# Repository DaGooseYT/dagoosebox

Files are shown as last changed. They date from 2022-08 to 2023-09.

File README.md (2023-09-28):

# DaGoose Box
<p align="center">
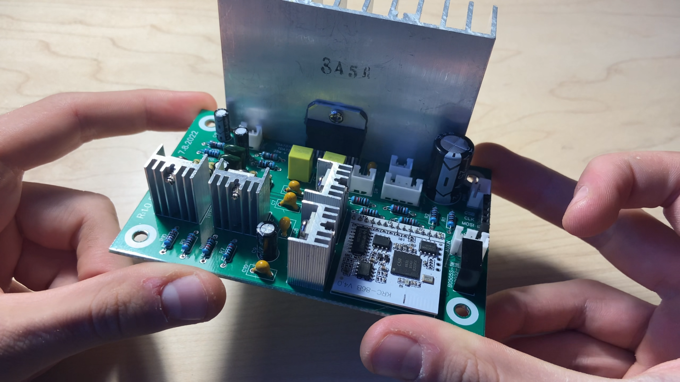
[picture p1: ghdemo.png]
  
</p>

A Hi-Fi linear Class AB amplifier with Bluetooth v4.0 compatibility and enhanced/3D stereo playback. Watch the video guide about it here: https://youtu.be/7peg0jiGp7A

## Features
- Very low THD (~0.02% @8ohm)
- High output power (~25.7w x2 @4ohm)
- Low cost design
- Simple PCB layout
- PCB uses very common passive componants

## Component list
- For the PCB components, please see the BoM located in `/BoM`

- Black box ($9.58): https://amzn.to/3PJ2Jeg
- 5.5mm barrel plug (~$0.60 each): https://amzn.to/3K8r4Zr 
- TDA7375AV ($6.43): https://bit.ly/3K4w6Go
- Heatsinks (~$3.00): No link since they came from salvaged electronics. Price is an estimated value.
- B0505S-1W (~$2.40 each): https://amzn.to/3wcbdDy
- KRC-86B v4.0 ($9.99): https://amzn.to/3pxKD3W
- Power switch (~$0.47 each): https://amzn.to/3AyoTv9
- Other PCB componants (~$6.00 total): No link since there are a variety of passive components. Price is an estimated value.
- 3.5mm audio jack (~$1.75 each): https://amzn.to/3AymmkJ
- Speaker wire terminals ($4.19): https://amzn.to/3QCLaxC
- TIP31C (x2, $1.46): https://bit.ly/3c4znce
- Custom PCB (~$4.00): Price is an estimated average and can vary on the basis of where you get it manufactured and other characteristics such as the solder mask. 

Estimated total component cost (No tax or shipping costs included): $49.87 USD<br />
*All components were priced on 7/25/2022. Prices of the components above are subject to change according to each seller's policies and inflation.<br />

You will also need a 16v 4.5A power supply. This is not calculated in the price list above. Here is the one I used for this project: https://amzn.to/3c4339q

## Mechanical info

- Box hole dimensions (measured from center of holes): 97mm x 56mm
- PCB board dimensions: 110mm x 70mm
- PCB screw holes diameter: 4mm
- Heatsink clearance in box (L x W x H): 84mm x 25mm x 76mm
- Required drill bits: 5mm, 8mm, 12mm

## Licensing
This repository is licensed under the GPL v3.0 license. Any images in this repository are licensed under CC BY-SA 3.0.

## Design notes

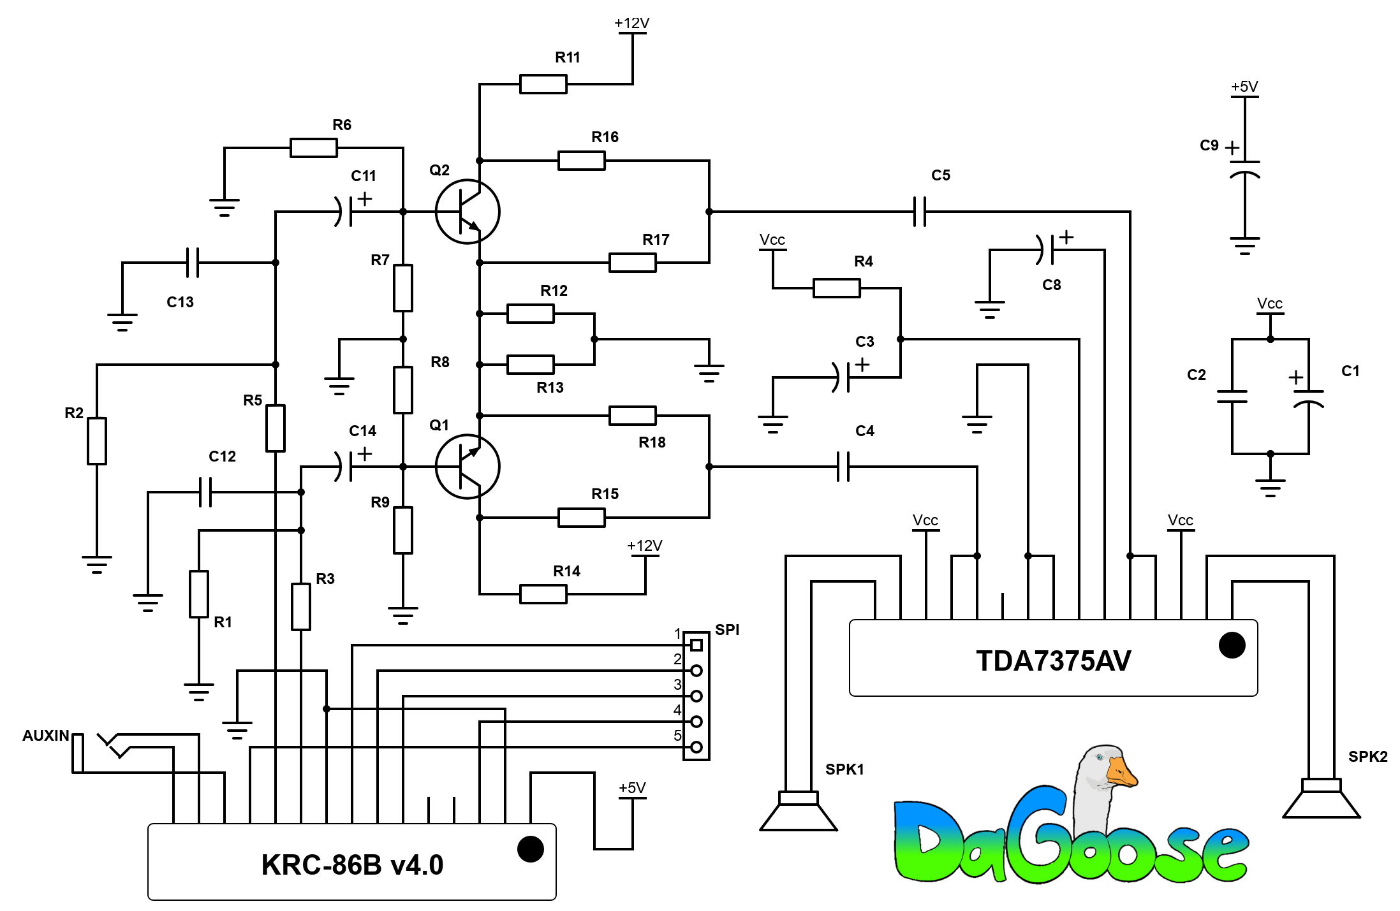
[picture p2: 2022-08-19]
schematic/schematic.png

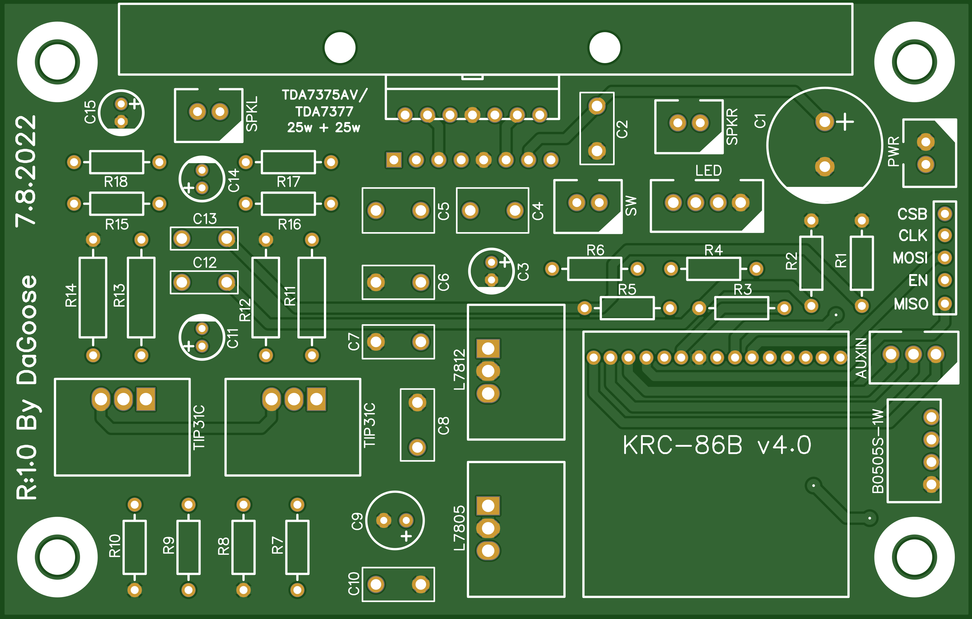
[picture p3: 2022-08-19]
PCB/top.png

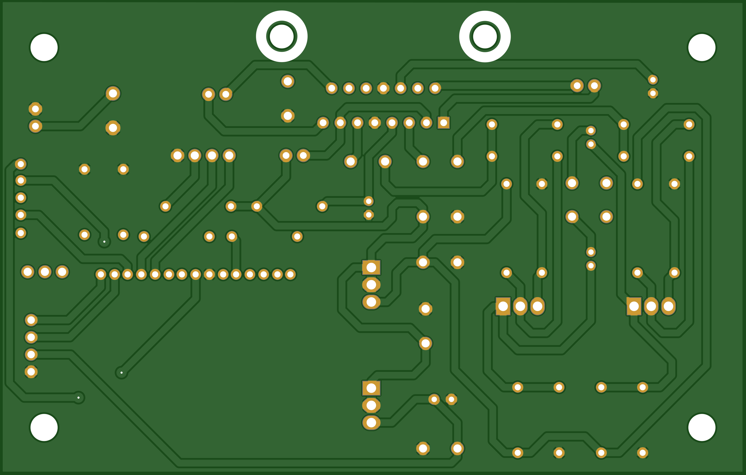
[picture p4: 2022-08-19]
PCB/bottom.png

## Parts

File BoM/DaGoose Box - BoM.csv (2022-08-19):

Componant | Description | Quantity | Manufacturer | Manufacturer Part Number | Additional Comment
R1, R2 | 1KΩ 1/4w ±1% | 2 | - | - | -
R3, R5 | 120Ω 1/4w ±1% | 2 | - | - | -
R4, R6, R7, R8, R9, R10 | 10KΩ 1/4w ±1% | 6 | - | - | -
R11, R12, R13, R14 | 56Ω 1/2w ±1% | 4 | - | - | -
R15, R16 | 100Ω 1/4w ±1% | 2 | - | - | -
R17, R18 | 8.2Ω 1/4w ±1% | 2 | - | - | -
C1 | 2200uF 25v ±10% | 1 | - | - | Electrolytic
C2, C6, C7, C8, C10 | 100nF 100v ±10% | 5 | - | - | Ceramic
C3, C11, C14 | 10uF 50v ±10% | 3 | - | - | Electrolytic
C4, C5 | 1uF 100v ±10% | 2 | - | - | CBB/Polyester Film
C9 | 470uF 10v ±10% | 1 | - | - | Electrolytic
C12, C13 | 33nF 100v ±10% | 2 | - | - | Polyester Film
C15 | 47uF 25v ±10% | 1 | - | - | Electrolytic
TIP31C | High power NPN transistor | 2 | STMicroelectronics | TIP31C | Used with small TO-220 heat sink (optional)
L7812 | 12v linear voltage regulator | 1 | STMicroelectronics | L7812 | Used with small TO-220 heat sink (required)
L7805 | 5v linear voltage regulator | 1 | STMicroelectronics | L7805 | Used with small TO-220 heat sink (optional)
B0505S-1W | 5v power isolator | 1 | K-CUT | B0505S-1WR3 | -
KRC-86B v4.0 | Bluetooth v4.0 module | 1 | - | KRC-86B v4.0 | Used 1x15 2mm pitch pin headers
TDA7375AV | 2x37w linear power amplifier | 1 | STMicroelectronics | E-TDA7375AV | Avoid buying fakes! Only buy from authorized distributors
SPKL, SPKR, SW, PWR | 1x2 2.54mm JST socket | 4 | JST | XH2.54-2p | -
AUXIN | 1x3 2.54mm JST socket | 1 | JST | XH2.54-3p | -
LED | 1x4 2.54mm JST socket | 1 | JST | XH2.54-4p | -
